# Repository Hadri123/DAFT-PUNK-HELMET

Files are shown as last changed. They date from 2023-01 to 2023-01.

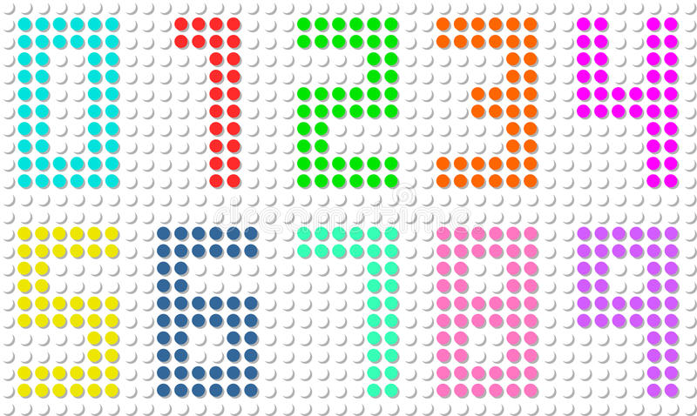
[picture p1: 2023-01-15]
img/5pixel_digit.jpg

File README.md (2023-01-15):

# DAFT PUNK HELMET
This repository contains the main code to realise light animation with the daft punk helmet.

## About the hardware
### Helmet
* Seven STL file to 3D print in PLA. Estimate time to print : 4 days  
 **If I had to redo it :** do not cut the front face
* Plexiglass
* [20% tint film](https://www.luminis-films.com/films-pour-vitrages/vitres-teintees/film-solaire-voiture/Film-teinte-pour-auto-Noir-moyen-AUTO-020i)
### Electronics
* Arduino Nano
* [HM10 Bluetooth Module](https://www.amazon.fr/gp/product/B06WGZB2N4/ref=ppx_yo_dt_b_asin_title_o01_s00?ie=UTF8&psc=1) to communicate with a smartphone with BLE Scanner 
* [1 meter of adressable LED strip](https://fr.aliexpress.com/item/32961181562.html?spm=a2g0o.order_list.0.0.12625e5bDeU7RO&gatewayAdapt=glo2fra) (60LED/m, white background) for the visor. The LED matrix size is 5x12.  
 **If I had to redo it :** use 2m of black background led strip to have a 5x16 matrix
* [2 led ring 6cm diameter](https://fr.aliexpress.com/item/32673883645.html?spm=a2g0o.order_list.0.0.12625e5bDeU7RO&gatewayAdapt=glo2fra) (24LED/ring) for the ears.
* [9V pile](https://www.amazon.fr/gp/product/B0774D64LT/ref=ppx_yo_dt_b_asin_title_o06_s00?ie=UTF8&psc=1) with it [connectors](https://www.amazon.fr/gp/product/B08ZD7ZB8T/ref=ppx_yo_dt_b_asin_title_o06_s00?ie=UTF8&psc=1)
* [Interuptor](https://fr.aliexpress.com/item/4001332967504.html?spm=a2g0o.order_list.0.0.12625e5bDeU7RO&gatewayAdapt=glo2fra)
* Dupont wires
* [Soldering kit](https://www.amazon.fr/gp/product/B088WMQ6GR/ref=ppx_yo_dt_b_asin_title_o04_s00?ie=UTF8&psc=1)

### PIN CONFIG
- RUBAN LED 6
- OREILLE G 5
- OREILLE D 4
- BLUETOOTH TX 2
- BLUETOOTH RX 3

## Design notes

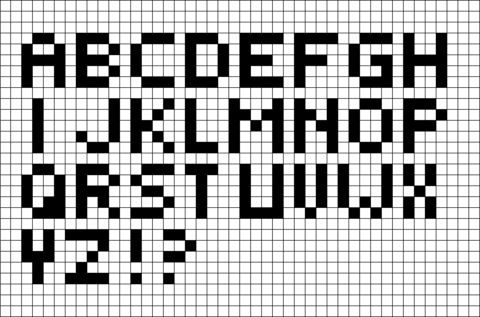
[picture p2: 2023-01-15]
img/5pixel_alphabet.jpg

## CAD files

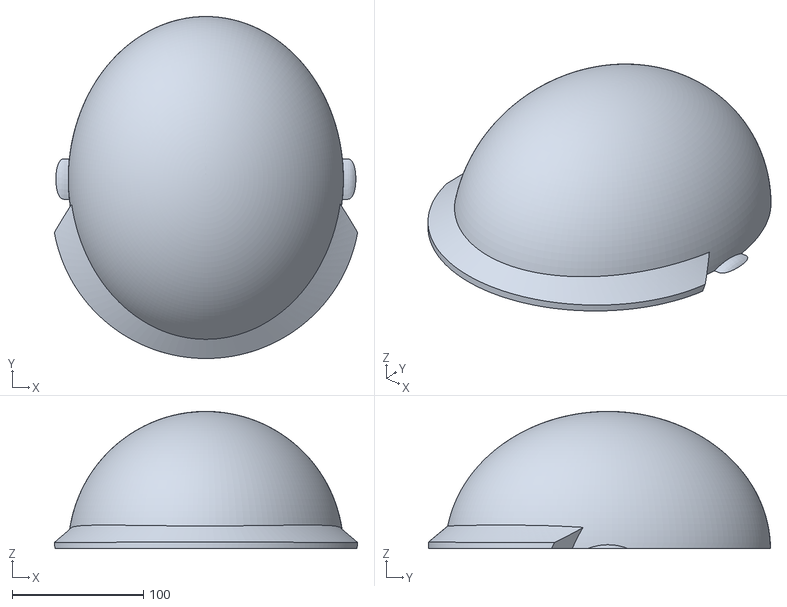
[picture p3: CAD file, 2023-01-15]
3D_files/daftThomas-top.stl
231.3 x 260.8 x 104.6

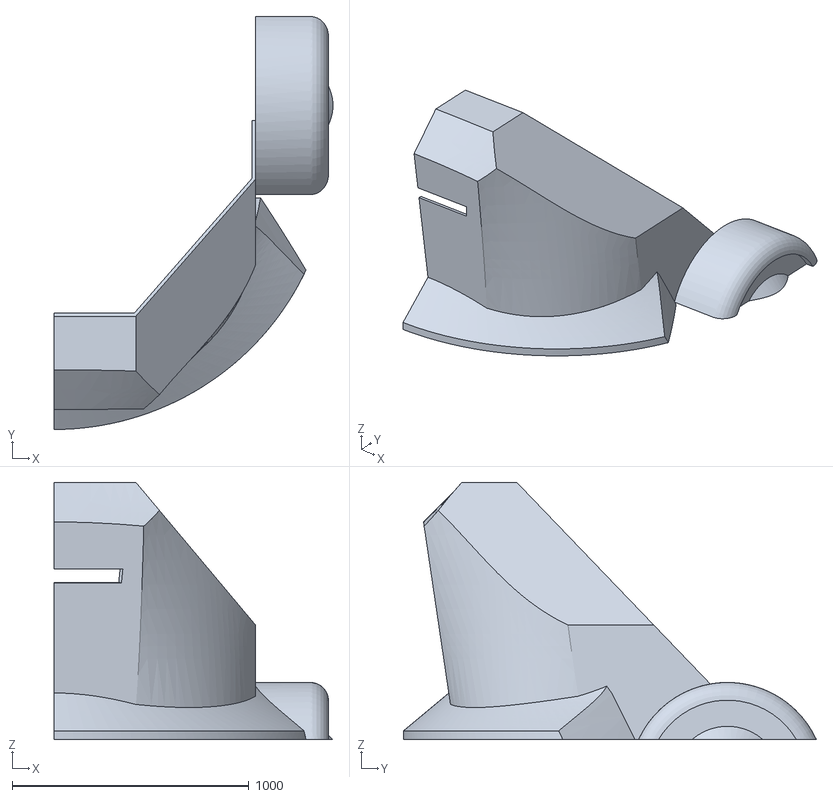
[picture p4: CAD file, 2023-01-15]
3D_files/daftThomas-btm_split-2.stl
1178.5 x 1744.7 x 1087.6

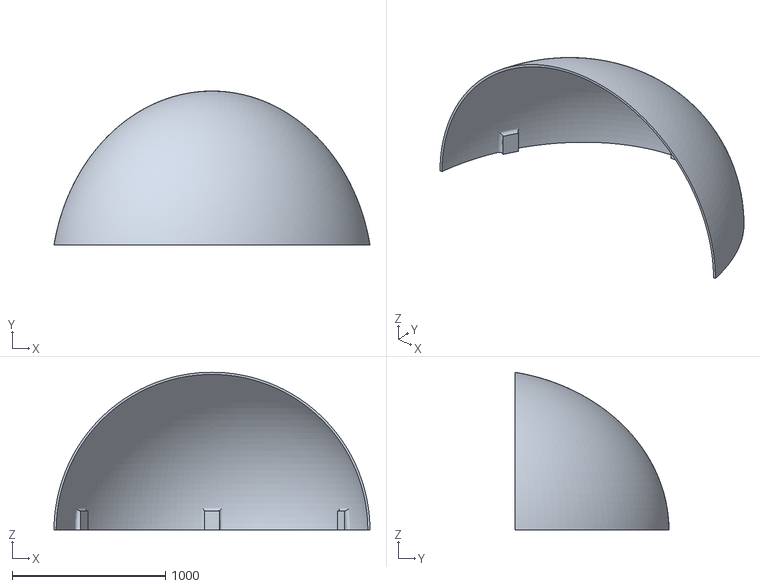
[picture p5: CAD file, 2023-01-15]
3D_files/daftThomas-top_split-1.stl
2060.7 x 1004.2 x 1027.2

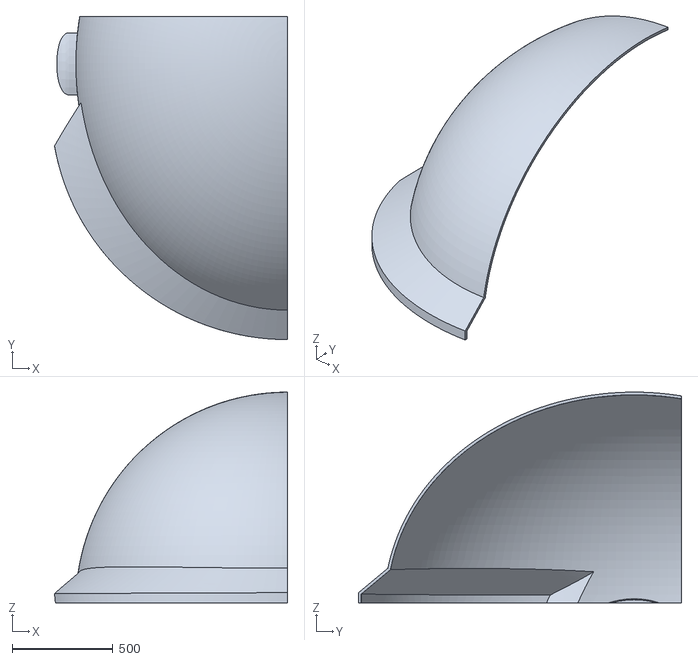
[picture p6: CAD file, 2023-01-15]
3D_files/daftThomas-top_split-3.stl
1156.5 x 1604.2 x 1046.5

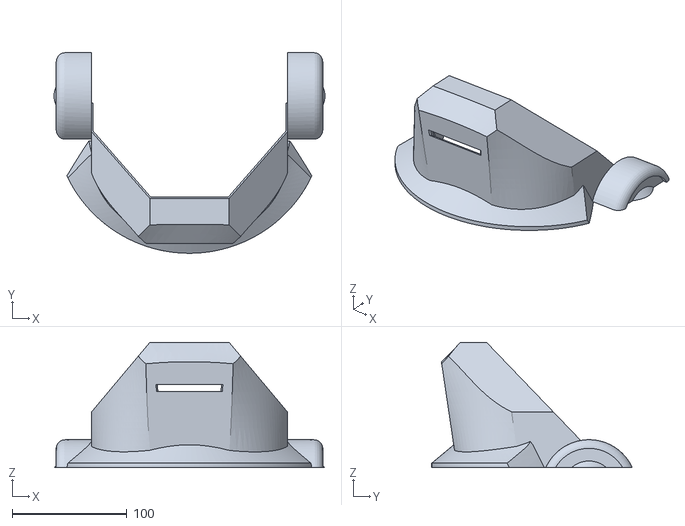
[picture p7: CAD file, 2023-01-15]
3D_files/daftThomas-btm.stl
235.7 x 174.5 x 108.8

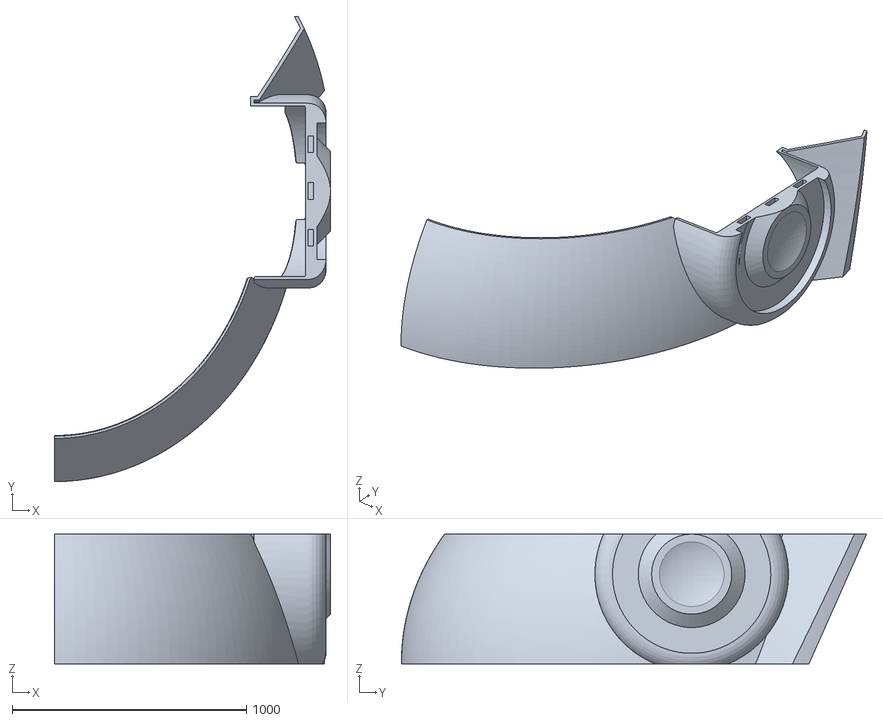
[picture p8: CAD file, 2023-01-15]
3D_files/daftThomas-mid_split-2.stl
1178.6 x 1986.7 x 554.4

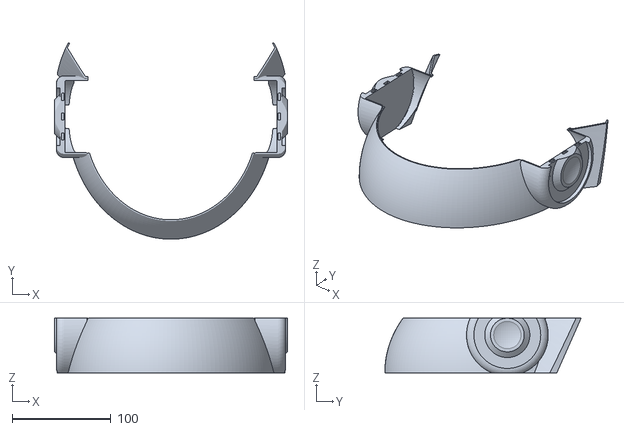
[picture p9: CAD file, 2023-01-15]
3D_files/daftThomas-mid.stl
235.7 x 198.7 x 55.4

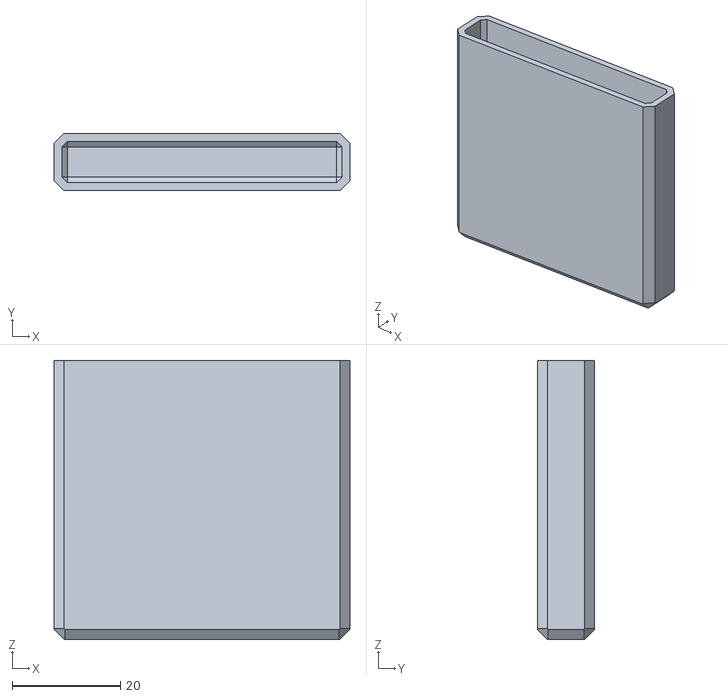
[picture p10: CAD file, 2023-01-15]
3D_files/lipoPocket2500.stl
54.6 x 10.6 x 51.5

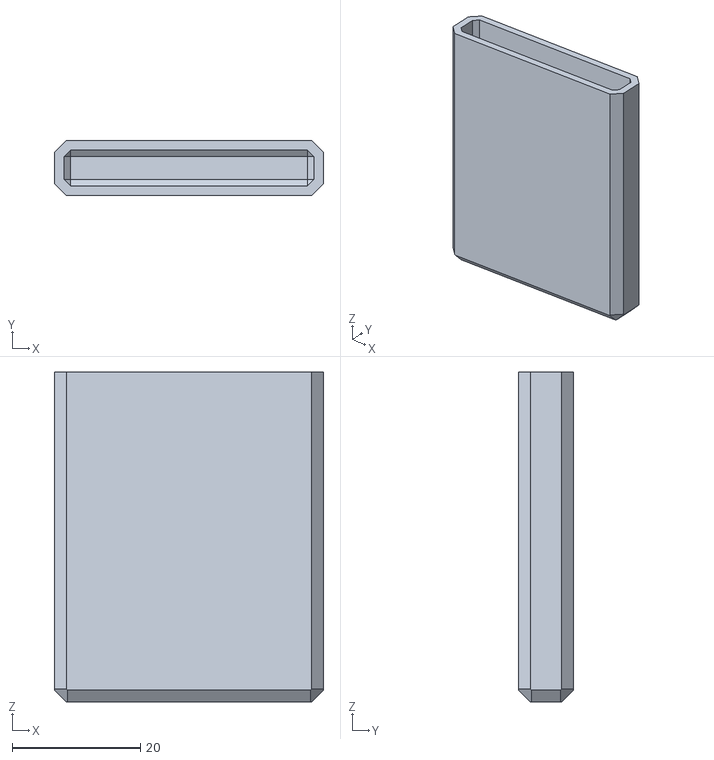
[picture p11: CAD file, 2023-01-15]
3D_files/lipoPocket2000.stl
42.0 x 8.60 x 51.5

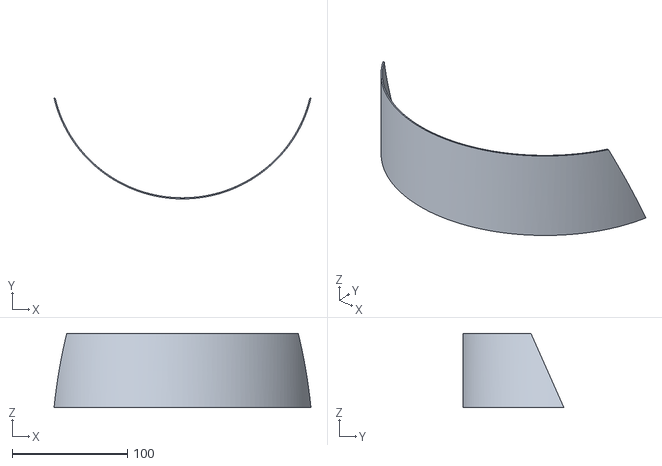
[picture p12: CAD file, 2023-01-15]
3D_files/daftThomas-shadesC.stl
223.2 x 87.6 x 64.5

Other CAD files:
3D_files/daftThomas-btm_split-1.stl
3D_files/daftThomas-top_split-2.stl
3D_files/daftThomas-mid_split-1.stl

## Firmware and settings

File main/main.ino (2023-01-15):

#include <FastLED.h>
#include <SoftwareSerial.h>
SoftwareSerial mySerial(2, 3); //TX, RX for bluetooth

// LED MATRIX
#define NUM_LEDS 60
#define BRIGHTNESS 64
#define DATA_PIN 6  // Digital In for Led Strip

// LED RING
#define NUM_LEDS_EAR 24
#define DATA_PIN_EAR_D 4  // Digital In for right ear
#define DATA_PIN_EAR_G 5  // Digital In for left ear

CRGBArray<NUM_LEDS> leds;
CRGBArray<NUM_LEDS_EAR> leds_ear_G;
CRGBArray<NUM_LEDS_EAR> leds_ear_D;

int XY(int x,int y)
{
   int i;
   int led_per_row = 12;
   int nb_row = 5;
   if((x > led_per_row) or (x < 1))  // depassement de rangée ( pour affichage des lettres)
      return(60);
   x = abs(x - led_per_row);
   y = abs(y - nb_row);
   i = x + led_per_row*y;
   if(y % 2 != 0)
   {
      i += led_per_row - 2*x -1;
   }
   return i;
}

void waiting(CRGB color, int waiting_speed)
{
  //WAITING
  int loop_length = 4;
  int idx_matrix = 1;
  int reverse_idx = 23;
  for(int clk = 0; clk < 24; clk++)
  {
    // EAR
    for(int loop_length_idx = 0; loop_length_idx < loop_length; loop_length_idx++)
    {
        light_up_offset_G(clk, loop_length_idx, color, 1);
        light_up_offset_D(reverse_idx, loop_length_idx, color, 0);
    }
    // LED MATRIX
      if(clk%2 == 0)
        idx_matrix += 1;
      
      leds[XY(idx_matrix,1)] = color;
      leds[XY(idx_matrix,2)] = color;
      leds[XY(idx_matrix,3)] = color;
      leds[XY(idx_matrix,4)] = color;
      leds[XY(idx_matrix,5)] = color;
      
      leds[XY(idx_matrix-1,1)] = color;
      leds[XY(idx_matrix-1,2)] = color;
      leds[XY(idx_matrix-1,3)] = color;
      leds[XY(idx_matrix-1,4)] = color;
      leds[XY(idx_matrix-1,5)] = color;
    
      leds[XY(idx_matrix-2,1)] = CRGB::Black;
      leds[XY(idx_matrix-2,2)] = CRGB::Black;
      leds[XY(idx_matrix-2,3)] = CRGB::Black;
      leds[XY(idx_matrix-2,4)] = CRGB::Black;
      leds[XY(idx_matrix-2,5)] = CRGB::Black;
   
    FastLED.show();
    delay(waiting_speed);
      
    light_up_offset_G(clk, loop_length, color, 0); 
    light_up_offset_G(clk, 0, CRGB::Black, 0);   
    light_up_offset_D(reverse_idx, loop_length, color, 1); 
    light_up_offset_D(reverse_idx, 0, CRGB::Black, 1);   
    FastLED.show();
    delay(waiting_speed);
    reverse_idx -= 1;
  }
  idx_matrix = 12;
  reverse_idx = 23;
  for(int clk = 0; clk < 24; clk++)
  {
    // EAR
    for(int loop_length_idx = 0; loop_length_idx < loop_length; loop_length_idx++)
    {
        light_up_offset_G(clk, loop_length_idx, color, 0);
        light_up_offset_D(reverse_idx, loop_length_idx, color, 1);
    }

      if(clk%2 == 0)
        idx_matrix -= 1;
      leds[XY(idx_matrix,1)] = color;
      leds[XY(idx_matrix,2)] = color;
      leds[XY(idx_matrix,3)] = color;
      leds[XY(idx_matrix,4)] = color;
      leds[XY(idx_matrix,5)] = color;
      
      leds[XY(idx_matrix+1,1)] = color;
      leds[XY(idx_matrix+1,2)] = color;
      leds[XY(idx_matrix+1,3)] = color;
      leds[XY(idx_matrix+1,4)] = color;
      leds[XY(idx_matrix+1,5)] = color;
    
      leds[XY(idx_matrix+2,1)] = CRGB::Black;
      leds[XY(idx_matrix+2,2)] = CRGB::Black;
      leds[XY(idx_matrix+2,3)] = CRGB::Black;
      leds[XY(idx_matrix+2,4)] = CRGB::Black;
      leds[XY(idx_matrix+2,5)] = CRGB::Black;
    
    FastLED.show();
    delay(waiting_speed);
     
    light_up_offset_G(clk, loop_length, color, 0); 
    light_up_offset_G(clk, 0, CRGB::Black, 0); 
    light_up_offset_D(reverse_idx, loop_length, color, 1); 
    light_up_offset_D(reverse_idx, 0, CRGB::Black, 1);     
    FastLED.show();
    delay(waiting_speed);
    reverse_idx -= 1;
  }
}

void my_random(CRGB color, int m_speed)
{
  init_leds_ears(CRGB::Black);
  init_leds(CRGB::Black);
  for(int k = 0; k < 40; k++)
    leds[random(0,NUM_LEDS)] = color;
  for(int k = 0; k < 15; k++)
  {
    leds_ear_G[random(0,NUM_LEDS_EAR)] = color;
    leds_ear_D[random(0,NUM_LEDS_EAR)] = color;
  }
  FastLED.show();
  delay(m_speed);
}

void initBluetooth()
{
  mySerial.begin(9600);
  Serial.begin(9600);
}
String i;
String updateSerial()
{
  if(mySerial.available())
  {
    i = mySerial.readString();
    Serial.write(mySerial.read());
    Serial.println(i);
    return i;
  }
  if(Serial.available())
  {
    mySerial.write(Serial.read());
  }
  return("");
}

String saved_word = "";
CRGB m_color = CRGB::Red;
int m_word_speed = 80;
int m_waiting_speed = 20;
int m_life_speed = 150;
int m_random_speed = 120;

void setup() { 
    initBluetooth();
    FastLED.addLeds<NEOPIXEL, DATA_PIN>(leds, NUM_LEDS);
    FastLED.addLeds<NEOPIXEL, DATA_PIN_EAR_D>(leds_ear_D, NUM_LEDS_EAR);
    FastLED.addLeds<NEOPIXEL, DATA_PIN_EAR_G>(leds_ear_G, NUM_LEDS_EAR);
    FastLED.setBrightness( BRIGHTNESS );
    Serial.println("SETUP");
    init_leds(CRGB::Black);
    init_leds_ears(CRGB::Black);
    life(m_color, m_life_speed);
    waiting(m_color, m_waiting_speed);
}



void loop() 
{ 
    String my_word = "";
    my_word = updateSerial();

    // save word to infinite repeat
    if(my_word == "blue")
      m_color = CRGB::Blue;
    else if(my_word == "red")
      m_color = CRGB::Red;
    else if(my_word == "green")
      m_color = CRGB::Green;
    else if(my_word == "purple")
      m_color = CRGB::Purple;
    else if(my_word == "orange")
      m_color = CRGB::Orange;
    else if(my_word == "white")
      m_color = CRGB::White;
    else if(my_word == "yellow")
      m_color = CRGB::Yellow;
    else if(my_word == "-")
    {
      m_word_speed *= 1.5;
      m_waiting_speed *= 1.5;
      m_life_speed *= 1.5;
      m_random_speed *= 1.5;
    }
    else if(my_word == "+")
    {
      m_word_speed /= 1.5;
      m_waiting_speed /= 1.5;
      m_life_speed /= 1.5;
      m_random_speed /= 1.5;
    }
    else if(my_word.length()>0)
      saved_word = my_word;

    
    if(saved_word == "1")
      eyes(m_color);
    else if(saved_word == "2")
      waiting(m_color, m_waiting_speed);
    else if(saved_word == "3")
      my_random(m_color, m_random_speed);
    else
    {
      init_leds(CRGB::Black);
      init_leds_ears(m_color);
      saved_word.toUpperCase();
      // array of size of each letter of the word
      int array_size_letters[saved_word.length()];
      
      int total_size_letters = 0;
      for(int letter_idx = 0; letter_idx < saved_word.length(); letter_idx++)
      {
        total_size_letters += size_letter((String)saved_word[letter_idx]);
        array_size_letters[letter_idx] = size_letter((String)saved_word[letter_idx]);
      }
      int size_letters = -1;
      int letter_idx = 0;
      for(int row_idx = 0; row_idx < 12 + total_size_letters + saved_word.length(); row_idx++)
      {
        size_letters = -1;
        for(int letter_idx = 0; letter_idx < saved_word.length(); letter_idx++)
        {
          if( row_idx > size_letters)
          {
            print_letter((String)saved_word[letter_idx], size_letters - row_idx + array_size_letters[letter_idx] + 1 + letter_idx, leds, m_color);
          }
          size_letters += array_size_letters[letter_idx];
        }
        FastLED.show();
        delay(m_word_speed);
        
        size_letters = -1;
        for(int letter_idx = 0; letter_idx < saved_word.length(); letter_idx++)
        {
          if( row_idx > size_letters)
          {
            print_letter((String)saved_word[letter_idx], size_letters - row_idx + array_size_letters[letter_idx] + 1 + letter_idx, leds, CRGB::Black);
            print_letter((String)saved_word[letter_idx], size_letters - row_idx + array_size_letters[letter_idx] + 1 - 1 + letter_idx, leds, m_color);
          }
          size_letters += array_size_letters[letter_idx];
        }
        FastLED.show();
        delay(m_word_speed);
      }
    }
    
}

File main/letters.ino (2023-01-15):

/*
 * 24/10/2022 - HD
 * 
 * One function describe how the led have to light on the right of the matrix (pixels 9 to 12).
 * Letters are describe with 5 lines.
 * Offset is used to scroll the letter to the right and create the animation
 * Each letter takes a different number of column on the matrix. Size_letter return it.
 * Print_letter function is a big switch case to call a letter function depending a char.
 * 
 */


void letter_A(int m_offset_a, CRGBArray<NUM_LEDS> m_leds, CRGB color)
{
  leds[XY(10 + m_offset_a,1)] = color; leds[XY(11 + m_offset_a,1)] = color; 
  leds[XY(9 + m_offset_a,2)] = color; leds[XY(12 + m_offset_a,2)] = color;
  leds[XY(9 + m_offset_a,3)] = color; leds[XY(11 + m_offset_a,3)] = color; leds[XY(10 + m_offset_a,3)] = color; leds[XY(12 + m_offset_a,3)] = color;
  leds[XY(9 + m_offset_a,4)] = color; leds[XY(12 + m_offset_a,4)] = color;
  leds[XY(9 + m_offset_a,5)] = color; leds[XY(12 + m_offset_a,5)] = color;
}

void letter_B(int m_offset_a, CRGBArray<NUM_LEDS> m_leds, CRGB color)
{
  leds[XY(9 + m_offset_a,1)] = color; leds[XY(10 + m_offset_a,1)] = color; leds[XY(11 + m_offset_a,1)] = color;
  leds[XY(9 + m_offset_a,2)] = color; leds[XY(12 + m_offset_a,2)] = color; 
  leds[XY(9 + m_offset_a,3)] = color; leds[XY(10 + m_offset_a,3)] = color; leds[XY(11 + m_offset_a,3)] = color;
  leds[XY(9 + m_offset_a,4)] = color; leds[XY(12 + m_offset_a,4)] = color; 
  leds[XY(9 + m_offset_a,5)] = color; leds[XY(10 + m_offset_a,5)] = color; leds[XY(11 + m_offset_a,5)] = color;
}

void letter_C(int m_offset_a, CRGBArray<NUM_LEDS> m_leds, CRGB color)
{
  leds[XY(11 + m_offset_a,1)] = color; leds[XY(12 + m_offset_a,1)] = color; 
  leds[XY(10 + m_offset_a,2)] = color;
  leds[XY(10 + m_offset_a,3)] = color;
  leds[XY(10 + m_offset_a,4)] = color;  
  leds[XY(11 + m_offset_a,5)] = color; leds[XY(12 + m_offset_a,5)] = color;
}

void letter_D(int m_offset_a, CRGBArray<NUM_LEDS> m_leds, CRGB color)
{
  leds[XY(9 + m_offset_a,1)] = color; leds[XY(10 + m_offset_a,1)] = color; leds[XY(11 + m_offset_a,1)] = color; 
  leds[XY(9 + m_offset_a,2)] = color; leds[XY(12 + m_offset_a,2)] = color; 
  leds[XY(9 + m_offset_a,3)] = color; leds[XY(12 + m_offset_a,3)] = color; 
  leds[XY(9 + m_offset_a,4)] = color; leds[XY(12 + m_offset_a,4)] = color; 
  leds[XY(9 + m_offset_a,5)] = color; leds[XY(10 + m_offset_a,5)] = color; leds[XY(11 + m_offset_a,5)] = color; 
}

void letter_E(int m_offset_a, CRGBArray<NUM_LEDS> m_leds, CRGB color)
{
  leds[XY(9 + m_offset_a,1)] = color; leds[XY(10 + m_offset_a,1)] = color; leds[XY(11 + m_offset_a,1)] = color; leds[XY(12 + m_offset_a,1)] = color; 
  leds[XY(9 + m_offset_a,2)] = color; 
  leds[XY(9 + m_offset_a,3)] = color; leds[XY(10 + m_offset_a,3)] = color; leds[XY(11 + m_offset_a,3)] = color; 
  leds[XY(9 + m_offset_a,4)] = color; 
  leds[XY(9 + m_offset_a,5)] = color; leds[XY(10 + m_offset_a,5)] = color; leds[XY(11 + m_offset_a,5)] = color; leds[XY(12 + m_offset_a,5)] = color; 
}

void letter_F(int m_offset_a, CRGBArray<NUM_LEDS> m_leds, CRGB color)
{
  leds[XY(9 + m_offset_a,1)] = color; leds[XY(10 + m_offset_a,1)] = color; leds[XY(11 + m_offset_a,1)] = color; leds[XY(12 + m_offset_a,1)] = color; 
  leds[XY(9 + m_offset_a,2)] = color; 
  leds[XY(9 + m_offset_a,3)] = color; leds[XY(10 + m_offset_a,3)] = color; leds[XY(11 + m_offset_a,3)] = color; 
  leds[XY(9 + m_offset_a,4)] = color; 
  leds[XY(9 + m_offset_a,5)] = color;
}

void letter_G(int m_offset_a, CRGBArray<NUM_LEDS> m_leds, CRGB color)
{
  leds[XY(10 + m_offset_a,1)] = color; leds[XY(11 + m_offset_a,1)] = color; leds[XY(12 + m_offset_a,1)] = color;
  leds[XY(9 + m_offset_a,2)] = color;
  leds[XY(9 + m_offset_a,3)] = color; leds[XY(11 + m_offset_a,3)] = color; leds[XY(12 + m_offset_a,3)] = color;
  leds[XY(9 + m_offset_a,4)] = color; leds[XY(12 + m_offset_a,4)] = color; 
  leds[XY(10 + m_offset_a,5)] = color; leds[XY(11 + m_offset_a,5)] = color; leds[XY(12 + m_offset_a,5)] = color;
}

void letter_H(int m_offset_a, CRGBArray<NUM_LEDS> m_leds, CRGB color)
{
  leds[XY(9 + m_offset_a,1)] = color; leds[XY(12 + m_offset_a,1)] = color;
  leds[XY(9 + m_offset_a,2)] = color; leds[XY(12 + m_offset_a,2)] = color;
  leds[XY(9 + m_offset_a,3)] = color; leds[XY(10 + m_offset_a,3)] = color; leds[XY(11 + m_offset_a,3)] = color; leds[XY(12 + m_offset_a,3)] = color;
  leds[XY(9 + m_offset_a,4)] = color; leds[XY(12 + m_offset_a,4)] = color;
  leds[XY(9 + m_offset_a,5)] = color; leds[XY(12 + m_offset_a,5)] = color;
}

void letter_I(int m_offset_a, CRGBArray<NUM_LEDS> m_leds, CRGB color)
{
  leds[XY(12 + m_offset_a,1)] = color; 
  leds[XY(12 + m_offset_a,2)] = color;
  leds[XY(12 + m_offset_a,3)] = color;
  leds[XY(12 + m_offset_a,4)] = color;
  leds[XY(12 + m_offset_a,5)] = color; 
}

void letter_J(int m_offset_a, CRGBArray<NUM_LEDS> m_leds, CRGB color)
{
  leds[XY(12 + m_offset_a,1)] = color; 
  leds[XY(12 + m_offset_a,2)] = color;
  leds[XY(12 + m_offset_a,3)] = color;
  leds[XY(9 + m_offset_a,4)] = color;  leds[XY(12 + m_offset_a,4)] = color;
  leds[XY(10 + m_offset_a,5)] = color; leds[XY(11 + m_offset_a,5)] = color;
}

void letter_K(int m_offset_a, CRGBArray<NUM_LEDS> m_leds, CRGB color)
{
  leds[XY(9 + m_offset_a,1)] = color; leds[XY(12 + m_offset_a,1)] = color;
  leds[XY(9 + m_offset_a,2)] = color; leds[XY(11 + m_offset_a,2)] = color;
  leds[XY(9 + m_offset_a,3)] = color; leds[XY(10 + m_offset_a,3)] = color;
  leds[XY(9 + m_offset_a,4)] = color; leds[XY(11 + m_offset_a,4)] = color;
  leds[XY(9 + m_offset_a,5)] = color; leds[XY(12 + m_offset_a,5)] = color;
}

void letter_L(int m_offset_a, CRGBArray<NUM_LEDS> m_leds, CRGB color)
{
  leds[XY(10 + m_offset_a,1)] = color; 
  leds[XY(10 + m_offset_a,2)] = color;
  leds[XY(10 + m_offset_a,3)] = color;
  leds[XY(10 + m_offset_a,4)] = color;
  leds[XY(10 + m_offset_a,5)] = color; leds[XY(11 + m_offset_a,5)] = color; leds[XY(12 + m_offset_a,5)] = color; 
}

void letter_M(int m_offset_a, CRGBArray<NUM_LEDS> m_leds, CRGB color)
{ 
  leds[XY(8 + m_offset_a,1)] = color; leds[XY(12 + m_offset_a,1)] = color;
  leds[XY(8 + m_offset_a,2)] = color; leds[XY(9 + m_offset_a,2)] = color; leds[XY(11 + m_offset_a,2)] = color; leds[XY(12 + m_offset_a,2)] = color;
  leds[XY(8 + m_offset_a,3)] = color; leds[XY(10 + m_offset_a,3)] = color; leds[XY(12 + m_offset_a,3)] = color;
  leds[XY(8 + m_offset_a,4)] = color; leds[XY(12 + m_offset_a,4)] = color;
  leds[XY(8 + m_offset_a,5)] = color; leds[XY(12 + m_offset_a,5)] = color;
}

void letter_N(int m_offset_a, CRGBArray<NUM_LEDS> m_leds, CRGB color)
{
  leds[XY(9 + m_offset_a,1)] = color; leds[XY(12 + m_offset_a,1)] = color; 
  leds[XY(9 + m_offset_a,2)] = color; leds[XY(10 + m_offset_a,2)] = color; leds[XY(12 + m_offset_a,2)] = color;
  leds[XY(9 + m_offset_a,3)] = color; leds[XY(11 + m_offset_a,3)] = color; leds[XY(12 + m_offset_a,3)] = color;
  leds[XY(9 + m_offset_a,4)] = color; leds[XY(12 + m_offset_a,4)] = color;
  leds[XY(9 + m_offset_a,5)] = color; leds[XY(12 + m_offset_a,5)] = color; 
}
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
